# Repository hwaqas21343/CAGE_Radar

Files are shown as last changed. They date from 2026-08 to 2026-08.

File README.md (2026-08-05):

# CAGE

A ground-based radar and lidar rig built on a 1:1 skeletal mockup of the Overseer UAV
(820 mm nose-to-tail, 760 mm wing-to-wing).

It does two jobs. The first is to demonstrate a layered detection stack of the kind
that would fly on the real aircraft. The second is to measure how well different RF
shielding materials (RAM foam, copper mesh, ferrite sheet) block radar detection.

It only receives. There is no jamming or active interference involved.

## Detection layers

| Layer | Sensor | Range | Role |
|---|---|---|---|
| Early warning | HLK-LD2451 x1 | 10-100 m | Long-range forward cone, +/-15 deg |
| Close tracking | HLK-LD2450 x3 | 0-6 m | 360 deg multi-target tracking, +/-60 deg each |
| Fine spatial | LDROBOT LD06 | 0.02-12 m | 360 deg 2D lidar sweep, ~0.8 deg resolution |

The three LD2450s sit 120 degrees apart in an equilateral triangle. Each one covers
+/-60 degrees, so between them they tile a full circle with no gap.

## Architecture

```
LD2450 x3 --UART--> ESP32-S3 #1 --+-- WiFi/UDP --> laptop (Python scope)
                                  +-- HTTP ------> phone  (browser scope)

LD2451 + LD06 --UART--> ESP32-S3 #2 -- WiFi/UDP --> laptop
```

Each board reads its sensors over hardware UART and tags every detection with the
sensor ID and that sensor's mounting angle. The viewers use the angle to rotate each
sensor's detections into a shared airframe frame, then merge them into one picture.

## What's here

| Path | What it is |
|---|---|
| `board1_web_radar/` | Main firmware. Three radars, self-hosted web scope, UDP output |
| `board1_final_3radar/` | Same three radars, UDP only |
| `board1_udp_radar/` | Single radar over UDP, used during bring-up |
| `board1_phase2_ld2450_single/` | Single radar, serial output only |
| `laptop/radar_plot_360.py` | Merged 360 degree scope |
| `CAGE code v1 (redundant).py` | Early single-sensor scope. Superseded, kept for reference |

## Wiring, board #1

The data lines cross over: the LD2450's TX goes to the pin the sketch calls RX.

| Sensor | Mounting | LD2450 TX to | LD2450 RX to | UART |
|---|---|---|---|---|
| A | 0 deg (forward) | GPIO 18 | GPIO 17 | UART1 |
| B | +120 deg | GPIO 16 | GPIO 15 | UART2 |
| C | -120 deg | GPIO 5 | GPIO 4 | UART0 |

All three share 5V and ground. Total draw is around 1 A. Use a 5V/2A supply, not a
PC USB port. A PC port can't feed three radars plus the ESP32, and the first thing
that fails is WiFi association, which looks like a network problem rather than a
power one.

Set `USB CDC On Boot` to `Enabled` in the IDE. Sensor C sits on UART0, which is
normally the serial console, so the console has to move to the S3's native USB. That
means you upload on one COM port and read the serial monitor on a different one.

## Patching existing library

This uses [rbegamer/HLK-LD2450](https://github.com/rbegamer/HLK-LD2450), which decodes
coordinates in a way that won't work for this use case. It reads X, Y and speed as two's complement, but
the sensor sends them as sign-magnitude: bit 15 is the sign, bits 0-14 the magnitude.
Left alone, a target at +300 mm comes out as -32468 mm.

In `LD2450.cpp`, in `ProcessSerialDataIntoRadarData()`:

```cpp
uint16_t rawX = rec_buf[index] | (rec_buf[index + 1] << 8);
target.x = (rawX & 0x8000) ? (int16_t)(rawX & 0x7FFF) : -(int16_t)(rawX & 0x7FFF);
// same for y and speed
```

`distance` is calculated from x and y, so it comes right on its own once those are
fixed. Reinstalling the library silently undoes this, so check it if readings suddenly
go strange.

Two smaller things about the same library. Its `valid` flag is set from
`resolution != 0` and can't be relied on, so filter on whether the distance is
physically plausible instead. And `RadarTarget` is declared inside the class, so it's
`LD2450::RadarTarget`, not `RadarTarget`.

I would like to add that this would not have been possible without [rbegamer/HLK-LD2450](https://github.com/rbegamer/HLK-LD2450) contributions
and work and I am in no way critiquing his efforts. I would highly recommend using their
code for this radar as it is by far the most complete available.

## Running it

Firmware:

1. Copy `secrets.example.h` to `secrets.h` in the sketch folder and put your WiFi
   details in it. `secrets.h` is gitignored.
2. Board `ESP32S3 Dev Module`, `USB CDC On Boot` enabled, 8 MB flash.
3. Install `HLK-LD2450` from Library Manager and patch it as above.
4. Upload.

For the phone view, open `http://<board-ip>/` in a browser. The ESP32 serves the page
itself so there's nothing to install. On iOS `http://cage.local/` also works; Android
is unreliable with `.local` so use the IP.

For the laptop view:

```bash
pip install matplotlib numpy
python laptop/radar_plot_360.py
```

## Filtering

Raw LD2450 output is messy. One person shows up as several targets because arms, legs
and torso all reflect separately, and anywhere two sensors overlap they both report
the same person independently. Both viewers run the same three steps before drawing
anything:

1. Detections within 0.6 m of each other are merged into one.
2. What's left is matched against existing tracks frame to frame and smoothed.
3. A track has to survive three frames before it gets drawn, which kills most ghosts.

The constants are at the top of each viewer if they need retuning.

## Progress

- [x] WiFi and UDP working
- [x] One LD2450 reading correctly (this is where the decode bug turned up)
- [x] Three LD2450s merged into one 360 degree view, plus the phone viewer
- [ ] LD2451 and LD06 on board #2
- [ ] Print the airframe, mount everything, run the shielding tests

## Radome note

At 24 GHz the wavelength inside PETG is about 7.2 mm. A wall in front of a radar
wants to be either much thinner than that (1 mm or less) or a multiple of a half
wave, so around 3.6 mm or 7.2 mm. Odd quarter-wave thicknesses near 1.8 mm and 5.4 mm
reflect the most and are worth avoiding. Print radar windows solid, since sparse
infill leaves air gaps that scatter unpredictably. I would not recommend using any
carbon fibre/ glass fibre based filaments as these will inhibit the accuracy 
and output of the radars.

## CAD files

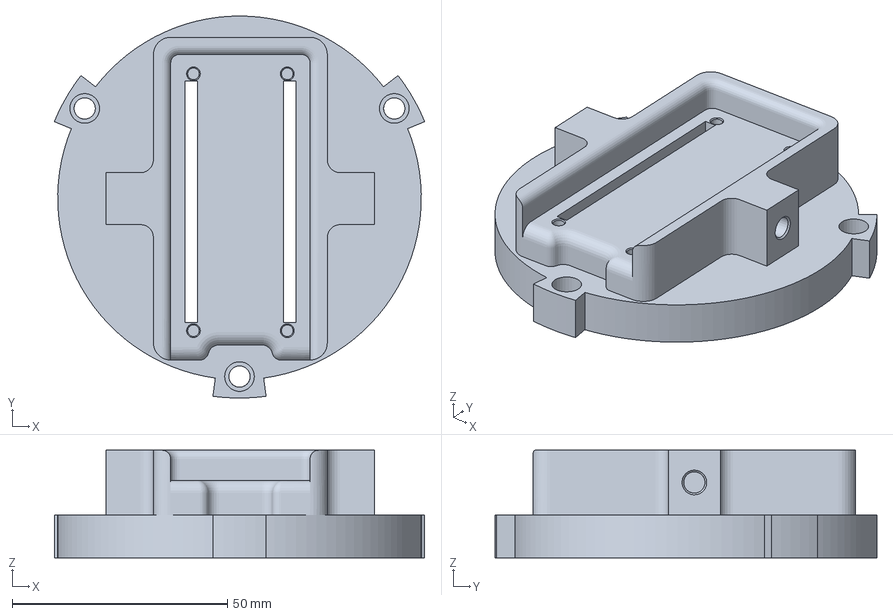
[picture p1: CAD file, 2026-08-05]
CAGE Prototype 2 Internal Mount.3mf
86.1 x 88.8 x 25.0 mm

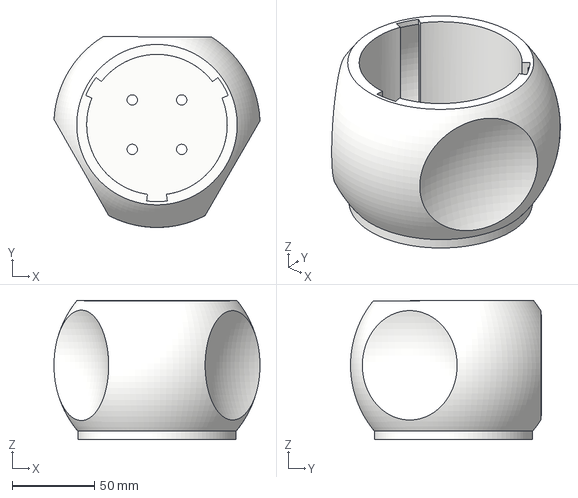
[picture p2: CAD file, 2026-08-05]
CAGE Prototype 2 Radome.3mf
125.1 x 115.9 x 84.5 mm

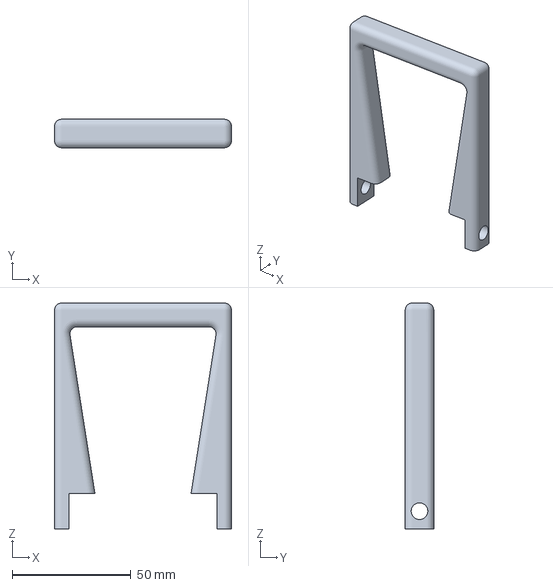
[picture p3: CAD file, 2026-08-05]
CAGE Prototype 2 Handle.3mf
74.4 x 12.0 x 95.0 mm

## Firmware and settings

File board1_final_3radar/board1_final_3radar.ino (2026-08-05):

// CAGE - Board #1 FINAL: 3x HLK-LD2450 in triangular layout -> WiFi/UDP -> laptop
//
// Layout: sensors mounted 120 degrees apart (equilateral triangle).
// Each LD2450 has +/-60 deg FOV, so 3 x 120 deg = full 360 coverage.
//
// Wiring (LD2450 TX -> ESP32 RX pin, LD2450 RX -> ESP32 TX pin):
//   Sensor A (  0 deg): TX -> GPIO 18, RX -> GPIO 17   (UART1)
//   Sensor B (+120 deg): TX -> GPIO 16, RX -> GPIO 15   (UART2)
//   Sensor C (-120 deg): TX -> GPIO 5,  RX -> GPIO 4    (UART0)
//   All: 5V -> 5V (shared), GND -> any GND pin.
//
// IDE setting REQUIRED: Tools -> USB CDC On Boot -> Enabled
//   (frees UART0 for sensor C; Serial Monitor runs over native USB)
//
// Library: rbegamer/HLK-LD2450 WITH the local sign-magnitude patch in LD2450.cpp.
//   If the library is ever reinstalled, re-apply the patch (see project notes).
//
// UDP packet, one per sensor per cycle (plain text):
//   "<sensorId>,<mountAngleDeg>:<x>,<y>,<dist>,<speed>;..."   mm and cm/s
//   e.g.  "A,0:252,335,419,0;-1101,1116,1568,-12"
//   or    "B,120:-"        when that sensor sees nothing

#include <WiFi.h>
#include <WiFiUdp.h>
#include <HardwareSerial.h>
#include <LD2450.h>

// ===== Network =====
// WiFi credentials live in secrets.h, which is gitignored.
// Copy secrets.example.h -> secrets.h and fill in your own values.
#include "secrets.h"

// ===== Sensors =====
#define NUM_SENSORS 3
#define LD2450_MAX_RANGE_MM 6000

struct RadarUnit {
  const char* id;        // tag sent in every packet
  int mountAngleDeg;     // mounting angle on the airframe (0 = forward)
  int rxPin, txPin;      // ESP32 pins (rx = sensor's TX arrives here)
  HardwareSerial serial;
  LD2450 radar;
};

RadarUnit units[NUM_SENSORS] = {
  { "A",    0, 18, 17, HardwareSerial(1), LD2450() },
  { "B",  120, 16, 15, HardwareSerial(2), LD2450() },
  { "C", -120,  5,  4, HardwareSerial(0), LD2450() },
};

WiFiUDP udp;

// LD2450 ships in single-target mode; switch to multi-target (persists in sensor flash).
void ld2450EnableMultiTarget(HardwareSerial &s) {
  uint8_t enterConfig[] = {0xFD,0xFC,0xFB,0xFA, 0x04,0x00, 0xFF,0x00, 0x01,0x00, 0x04,0x03,0x02,0x01};
  uint8_t multiTarget[] = {0xFD,0xFC,0xFB,0xFA, 0x02,0x00, 0x90,0x00, 0x04,0x03,0x02,0x01};
  uint8_t exitConfig[]  = {0xFD,0xFC,0xFB,0xFA, 0x02,0x00, 0xFE,0x00, 0x04,0x03,0x02,0x01};
  s.write(enterConfig, sizeof(enterConfig)); s.flush(); delay(100);
  s.write(multiTarget, sizeof(multiTarget)); s.flush(); delay(100);
  s.write(exitConfig,  sizeof(exitConfig));  s.flush(); delay(100);
  while (s.available()) s.read();
}

void setup() {
  Serial.begin(115200);
  // With USB CDC, give the host a moment to open the port or the first
  // prints are lost. Timeout so the board still runs headless.
  unsigned long t0 = millis();
  while (!Serial && millis() - t0 < 3000) delay(10);
  delay(200);
  Serial.println("CAGE Board #1 - 3x LD2450 triangular array");

  for (int i = 0; i < NUM_SENSORS; i++) {
    units[i].serial.begin(256000, SERIAL_8N1, units[i].rxPin, units[i].txPin);
    delay(100);
    ld2450EnableMultiTarget(units[i].serial);
    units[i].radar.begin(units[i].serial);
    Serial.printf("  sensor %s @ %+d deg on RX=%d TX=%d\n",
                  units[i].id, units[i].mountAngleDeg, units[i].rxPin, units[i].txPin);
  }

  Serial.printf("Connecting to %s", WIFI_SSID);
  WiFi.begin(WIFI_SSID, WIFI_PASS);
  while (WiFi.status() != WL_CONNECTED) {
    delay(400);
    Serial.print(".");
  }
  Serial.printf("\nConnected. ESP32 IP: %s -> %s:%u\n",
                WiFi.localIP().toString().c_str(), LAPTOP_IP, UDP_PORT);
}

void loop() {
  static unsigned long lastSend = 0;
  static unsigned long lastDbg = 0;

  // Keep every sensor's buffer drained each pass
  for (int i = 0; i < NUM_SENSORS; i++) units[i].radar.read();

  if (millis() - lastSend < 50) return;   // ~20 packets/s per sensor
  lastSend = millis();

  for (int i = 0; i < NUM_SENSORS; i++) {
    String payload = String(units[i].id) + "," + String(units[i].mountAngleDeg) + ":";
    int count = 0;
    for (int t = 0; t < 3; t++) {
      LD2450::RadarTarget tg = units[i].radar.getTarget(t);
      if (tg.distance == 0 || tg.distance > LD2450_MAX_RANGE_MM) continue;
      if (count > 0) payload += ";";
      payload += String(tg.x) + "," + String(tg.y) + "," + String(tg.distance) + "," + String(tg.speed);
      count++;
    }
    if (count == 0) payload += "-";

    udp.beginPacket(LAPTOP_IP, UDP_PORT);
    udp.print(payload);
    udp.endPacket();
  }

  // Debug heartbeat twice a second
  if (millis() - lastDbg >= 500) {
    lastDbg = millis();
    Serial.printf("WiFi=%d  sending 3 sensor packets to %s:%u\n",
                  WiFi.status(), LAPTOP_IP, UDP_PORT);
  }
}

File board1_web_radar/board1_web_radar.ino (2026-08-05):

// CAGE - Board #1: 3x HLK-LD2450 triangular array
//   -> serves a phone-friendly web radar scope over WiFi
//   -> ALSO keeps sending UDP, so the Python scope still works
//
// Open on your phone:  http://<board-ip>/     (IP is printed to Serial)
//                or:   http://cage.local/     (iOS/macOS; Android often needs the IP)
//
// Wiring (LD2450 TX -> ESP32 RX pin, LD2450 RX -> ESP32 TX pin):
//   Sensor A (   0 deg): TX -> GPIO 18, RX -> GPIO 17   (UART1)
//   Sensor B (+120 deg): TX -> GPIO 16, RX -> GPIO 15   (UART2)
//   Sensor C (-120 deg): TX -> GPIO 5,  RX -> GPIO 4    (UART0)
//   All: 5V shared, GND shared.
//
// IDE setting REQUIRED: Tools -> USB CDC On Boot -> Enabled
// Library: rbegamer/HLK-LD2450 WITH the local sign-magnitude patch.

#include <WiFi.h>
#include <WiFiUdp.h>
#include <WebServer.h>
#include <ESPmDNS.h>
#include <HardwareSerial.h>
#include <LD2450.h>

// ===== Network =====
// WiFi credentials live in secrets.h, which is gitignored.
// Copy secrets.example.h -> secrets.h and fill in your own values.
#include "secrets.h"

#define NUM_SENSORS 3
#define LD2450_MAX_RANGE_MM 6000

struct RadarUnit {
  const char* id;
  int mountAngleDeg;
  int rxPin, txPin;
  HardwareSerial serial;
  LD2450 radar;
};

RadarUnit units[NUM_SENSORS] = {
  { "A",    0, 18, 17, HardwareSerial(1), LD2450() },
  { "B",  120, 16, 15, HardwareSerial(2), LD2450() },
  { "C", -120,  5,  4, HardwareSerial(0), LD2450() },
};

WiFiUDP udp;
WebServer server(80);

// ---------- the web app (served from flash) ----------
static const char PAGE[] PROGMEM = R"rawliteral(
<!DOCTYPE html><html><head>
<meta charset="utf-8">
<meta name="viewport" content="width=device-width,initial-scale=1,maximum-scale=1,user-scalable=no">
<title>CAGE Radar</title>
<style>
  :root { --g:#00ff41; --dim:#0a5c1e; --bg:#001a00; }
  * { box-sizing:border-box; -webkit-tap-highlight-color:transparent; }
  html,body { margin:0; height:100%; background:#000; color:var(--g);
    font-family:Helvetica,Arial,sans-serif; font-weight:bold; overflow:hidden; }
  #wrap { display:flex; flex-direction:column; height:100%; }
  header { padding:8px 12px 2px; font-size:14px; letter-spacing:.5px; }
  #scope { flex:1; display:block; width:100%; }
  footer { padding:6px 12px 10px; font-size:12px; opacity:.85;
    display:flex; gap:14px; flex-wrap:wrap; }
  .bad { color:#ff5555; }
</style></head><body>
<div id="wrap">
  <header>CAGE &middot; 360 SCOPE</header>
  <canvas id="scope"></canvas>
  <footer>
    <span id="stat">connecting...</span>
    <span id="cnt"></span>
    <span id="raw"></span>
  </footer>
</div>
<script>
const MAXR = 6.0;
// same filter constants as the Python scope
const CLUSTER = 0.60, MATCH = 0.90, SMOOTH = 0.35;
const MINHITS = 3, MAXMISS = 10, TRAIL = 8;

const cv = document.getElementById('scope');
const ctx = cv.getContext('2d');
let W = 0, H = 0, cx = 0, cy = 0, R = 0;

function resize() {
  const dpr = window.devicePixelRatio || 1;
  const r = cv.getBoundingClientRect();
  cv.width = r.width * dpr; cv.height = r.height * dpr;
  ctx.setTransform(dpr, 0, 0, dpr, 0, 0);
  W = r.width; H = r.height;
  cx = W / 2; cy = H / 2; R = Math.min(W, H) * 0.45;
}
window.addEventListener('resize', resize);

// polar (theta rad, 0=up, clockwise) + range m  ->  screen px
function px(th, rm) {
  const k = (rm / MAXR) * R;
  return [cx + k * Math.sin(th), cy - k * Math.cos(th)];
}

let tracks = [], rawCount = 0, ok = false;

function cluster(pts) {
  const g = [];
  for (const p of pts) {
    let hit = null;
    for (const c of g) {
      if (Math.hypot(p[0] - c.x, p[1] - c.y) <= CLUSTER) { hit = c; break; }
    }
    if (hit) {
      hit.pts.push(p);
      hit.x = hit.pts.reduce((s, q) => s + q[0], 0) / hit.pts.length;
      hit.y = hit.pts.reduce((s, q) => s + q[1], 0) / hit.pts.length;
    } else g.push({ x: p[0], y: p[1], pts: [p] });
  }
  return g.map(c => [c.x, c.y]);
}

function step(cs) {
  const left = cs.slice();
  for (const t of tracks) {
    let bi = -1, bd = MATCH;
    for (let i = 0; i < left.length; i++) {
      const d = Math.hypot(left[i][0] - t.x, left[i][1] - t.y);
      if (d < bd) { bd = d; bi = i; }
    }
    if (bi >= 0) {
      const [x, y] = left.splice(bi, 1)[0];
      t.x += SMOOTH * (x - t.x); t.y += SMOOTH * (y - t.y);
      t.hits++; t.miss = 0;
      t.tail.push([t.x, t.y]); if (t.tail.length > TRAIL) t.tail.shift();
    } else t.miss++;
  }
  for (const c of left) tracks.push({ x: c[0], y: c[1], hits: 1, miss: 0, tail: [[c[0], c[1]]] });
  tracks = tracks.filter(t => t.miss <= MAXMISS);
}

function draw() {
  ctx.clearRect(0, 0, W, H);

  // scope face
  ctx.beginPath(); ctx.arc(cx, cy, R, 0, 6.284);
  ctx.fillStyle = 'rgba(0,40,0,.55)'; ctx.fill();

  // range rings
  ctx.strokeStyle = '#0a5c1e'; ctx.lineWidth = 1;
  ctx.font = '10px Helvetica,Arial'; ctx.fillStyle = 'rgba(0,255,65,.65)';
  for (let m = 1; m <= MAXR; m++) {
    const k = (m / MAXR) * R;
    ctx.beginPath(); ctx.arc(cx, cy, k, 0, 6.284); ctx.stroke();
    ctx.fillText(m + 'm', cx + 3, cy - k + 11);
  }
  // spokes every 30 deg
  for (let d = 0; d < 360; d += 30) {
    const th = d * Math.PI / 180;
    const [x, y] = px(th, MAXR);
    ctx.beginPath(); ctx.moveTo(cx, cy); ctx.lineTo(x, y); ctx.stroke();
  }
  // bearing labels
  ctx.fillStyle = 'rgba(0,255,65,.8)'; ctx.textAlign = 'center';
  for (let d = 0; d < 360; d += 90) {
    const th = d * Math.PI / 180;
    const [x, y] = px(th, MAXR * 1.1);
    ctx.fillText(d === 0 ? 'FWD' : d + '°',
                 Math.max(14, Math.min(W - 14, x)), Math.max(12, Math.min(H - 4, y)));
  }
  ctx.textAlign = 'left';

  // sensor at origin
  ctx.beginPath(); ctx.moveTo(cx, cy - 8); ctx.lineTo(cx - 7, cy + 6); ctx.lineTo(cx + 7, cy + 6);
  ctx.closePath(); ctx.fillStyle = '#00ff41'; ctx.fill();

  // blips + fading tails
  let shown = 0;
  for (const t of tracks) {
    if (t.hits < MINHITS) continue;
    shown++;
    for (let i = 0; i < t.tail.length; i++) {
      const [x, y] = t.tail[i];
      const a = 0.15 + 0.85 * ((i + 1) / t.tail.length);
      const rm = Math.hypot(x, y), th = Math.atan2(x, y);
      if (rm > MAXR) continue;
      const [sx, sy] = px(th, rm);
      ctx.beginPath();
      ctx.arc(sx, sy, i === t.tail.length - 1 ? 7 : 4, 0, 6.284);
      ctx.fillStyle = 'rgba(0,255,65,' + a.toFixed(2) + ')';
      ctx.fill();
    }
  }

  document.getElementById('cnt').textContent = 'targets: ' + shown;
  document.getElementById('raw').textContent = 'raw: ' + rawCount;
  const st = document.getElementById('stat');
  st.textContent = ok ? 'live' : 'no data';
  st.className = ok ? '' : 'bad';
}

async function tick() {
  try {
    const r = await fetch('/data', { cache: 'no-store' });
    const j = await r.json();
    rawCount = j.t.length;
    step(cluster(j.t));
    ok = true;
  } catch (e) { ok = false; }
  draw();
}

resize();
draw();
setInterval(tick, 100);
</script></body></html>
)rawliteral";
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

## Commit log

2026-08-05 Initial commit: CAGE radar rig firmware and viewers
    Three HLK-LD2450 radars in a 120-degree triangular layout on an ESP32-S3,
    covering a full 360 degrees. Includes:
    - board1_web_radar: main firmware, serves a phone radar scope over HTTP
    and streams UDP at the same time
    - board1_final_3radar: same three radars, UDP only
    - board1_udp_radar / board1_phase2_ld2450_single: bring-up sketches
    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
2026-08-05 Mark the v1 single-sensor scope as redundant
    It predates the triangular three-radar layout and only parses the old
    packet format, so it no longer runs against current firmware. Kept for
    reference and noted as such in the README.
2026-08-05 Add warning about carbon/glass fibre filaments
    Added a warning against using carbon fibre/glass fibre filaments for radar applications due to accuracy issues.
2026-08-05 CAD files to 3D print housing
    [C AGE Prototype 2_Configuration 1_Base.3mf, C AGE Prototype 2_Configuration 1_Body23.3mf, C AGE Prototype 2_Configuration 1_Radome.3mf]
2026-08-05 Create 3D Printable housing
2026-08-05 CAGE housing 3D printable files
    [CAGE Prototype 2 Handle.3mf, CAGE Prototype 2 Internal Mount.3mf, CAGE Prototype 2 Radome.3mf]
